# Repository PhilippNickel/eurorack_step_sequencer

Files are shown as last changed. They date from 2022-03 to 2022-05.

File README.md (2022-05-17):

# eurorack_step_sequencer
Open Hardware 8 Channel Eurorack Step Sequencer
# Introduction
These are the KiCad PCB files for a DIY eurorack 8 channel step sequencer module. The heart of the system is an Atmega16A and it features a small i2c OLED Display to modify certain settings. The manufacturing, firmware and testing are still work in progress, photos, videos and firmware will follow.
# 3d Model
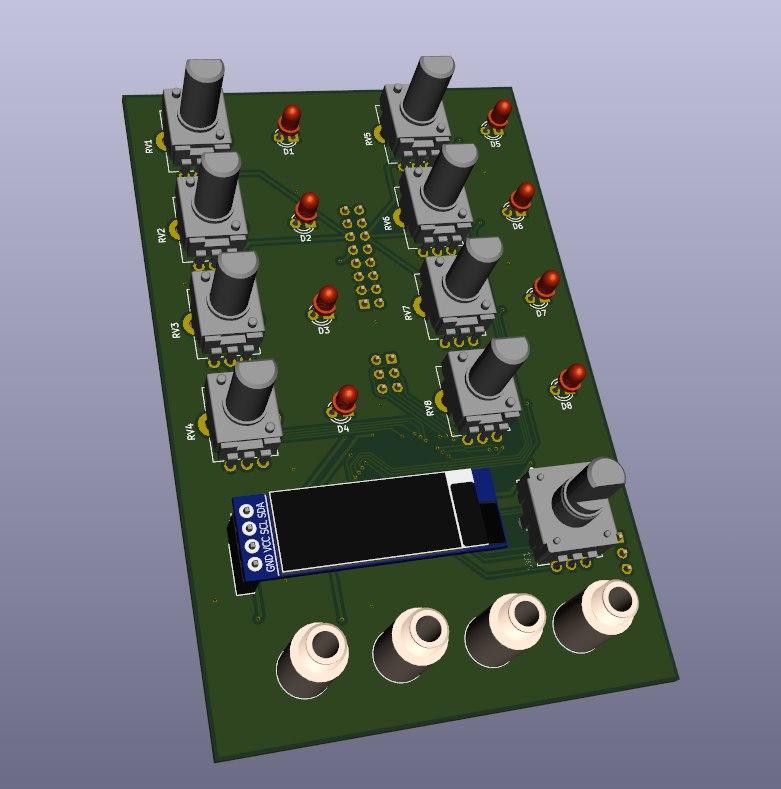
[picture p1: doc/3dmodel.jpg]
3d Model without faceplate 3dmodel


# Schematic
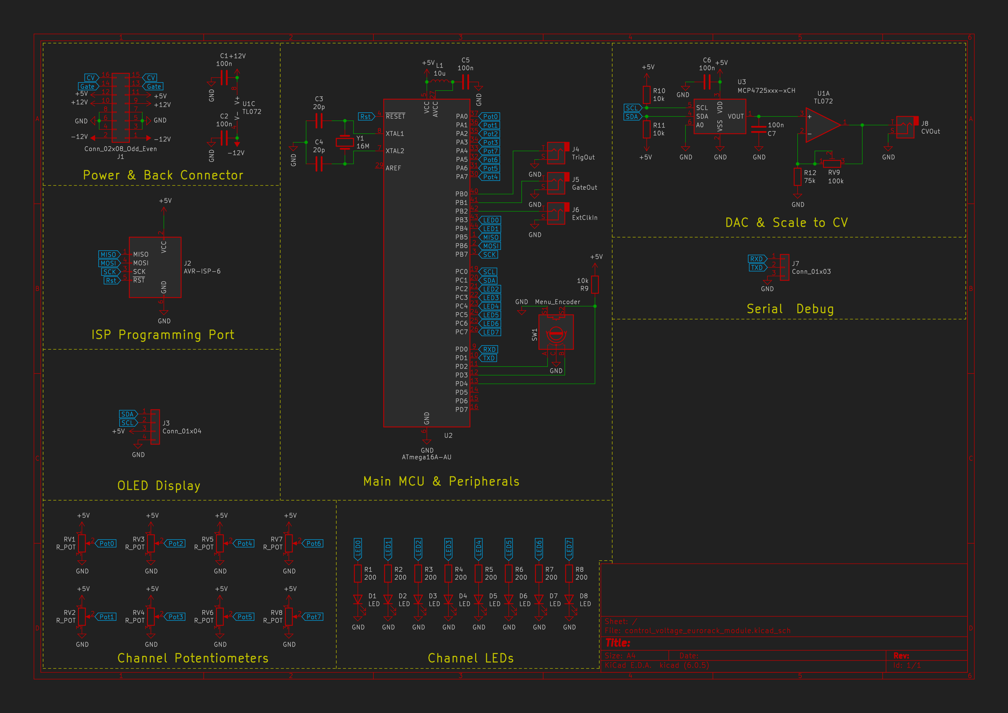
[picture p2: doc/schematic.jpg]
Schematic schematic


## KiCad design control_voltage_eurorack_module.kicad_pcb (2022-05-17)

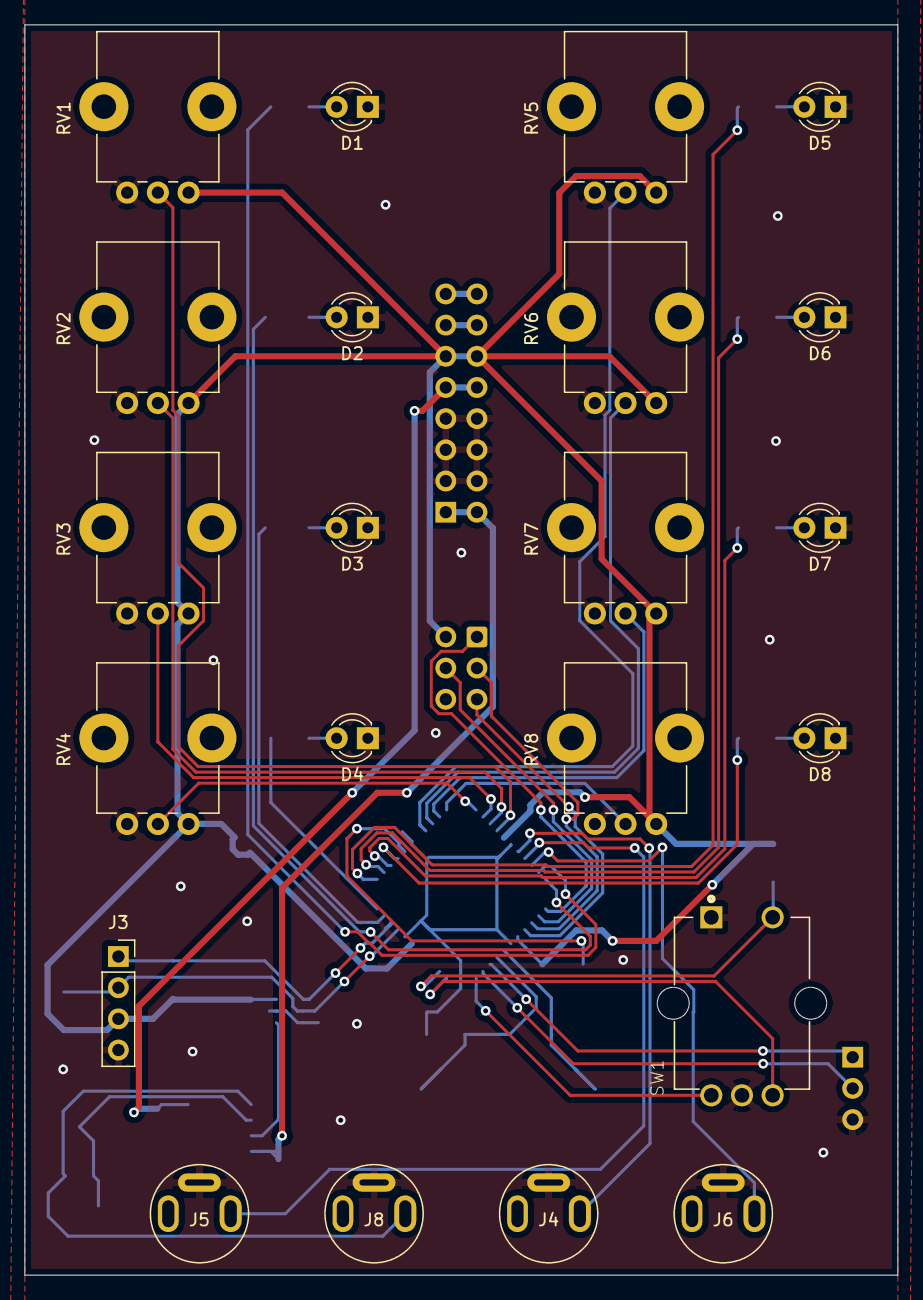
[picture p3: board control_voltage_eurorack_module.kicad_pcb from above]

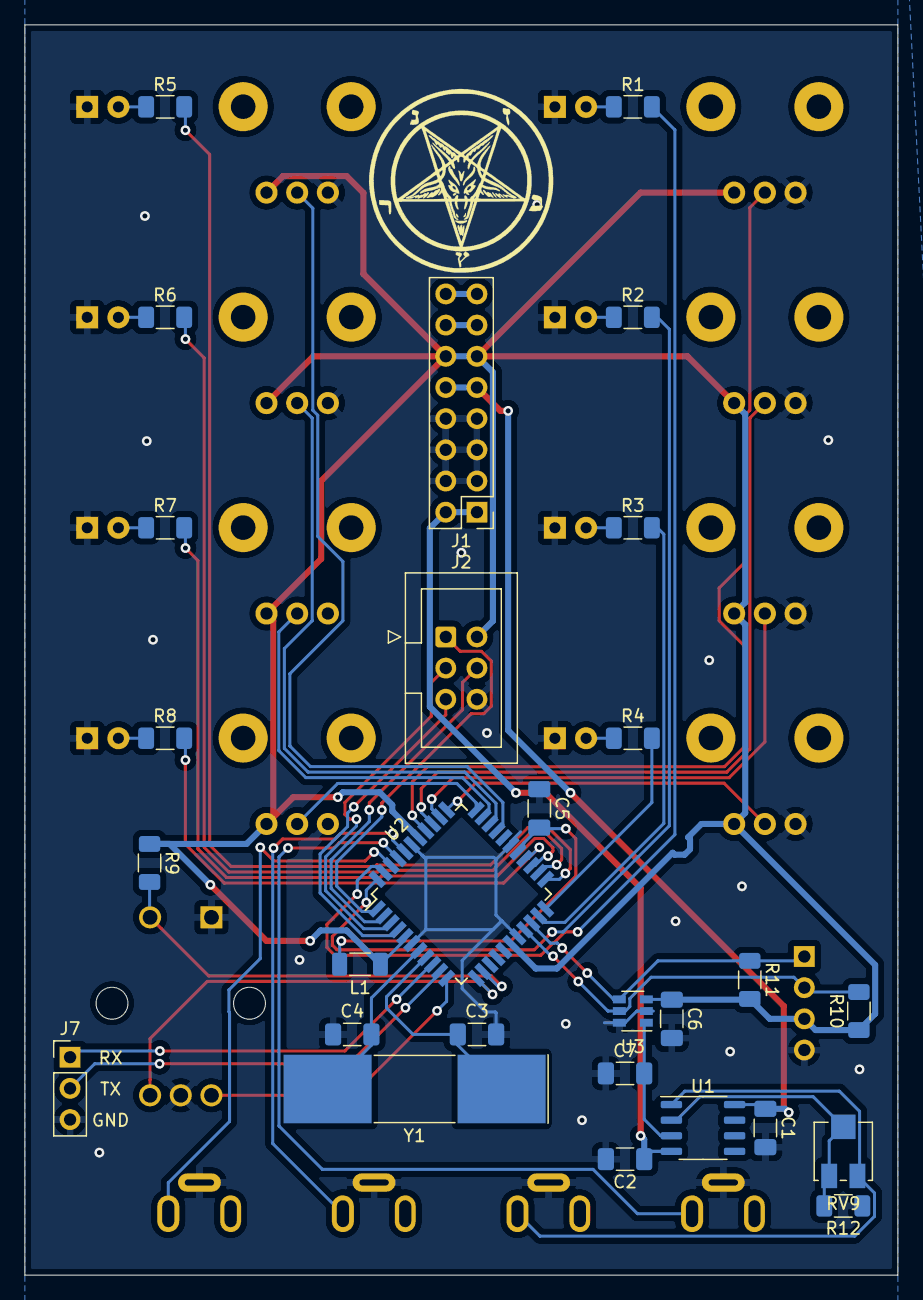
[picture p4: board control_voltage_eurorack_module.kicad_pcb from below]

Board: 2 copper layers, 71.1 x 101.9 mm, 50 parts (28 on the bottom side), 50 nets.

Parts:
C1, C2, C5, C6, C7: 100n; C_1206_3216Metric_Pad1.33x1.80mm_HandSolder
C3, C4: 20p; C_1206_3216Metric_Pad1.33x1.80mm_HandSolder
D1, D2, D3, D4, D5, D6, D7, D8: LED; LED_D3.0mm
J1: Conn_02x08_Odd_Even; PinHeader_2x08_P2.54mm_Vertical
J2: AVR-ISP-6; IDC-Header_2x03_P2.54mm_Vertical
J3: Conn_01x04; PinSocket_1x04_P2.54mm_Vertical
J4: TrigOut; Jack_3.5mm_VERTICAL
J5: GateOut; Jack_3.5mm_VERTICAL
J6: ExtClkIn; Jack_3.5mm_VERTICAL
J7: Conn_01x03; PinHeader_1x03_P2.54mm_Vertical
J8: CVOut; Jack_3.5mm_VERTICAL
L1: 10u; L_1206_3216Metric_Pad1.22x1.90mm_HandSolder
R1, R2, R3, R4, R5, R6, R7, R8: 200; R_1206_3216Metric_Pad1.30x1.75mm_HandSolder
R9, R10, R11: 10k; R_1206_3216Metric_Pad1.30x1.75mm_HandSolder
R12: 75k; R_1206_3216Metric_Pad1.30x1.75mm_HandSolder
RV1, RV2, RV3, RV4, RV5, RV6, RV7, RV8: R_POT; Potentiometer_Bourns_PTV09A-1_Single_Vertical
RV9: 100k; Potentiometer_Bourns_3314J_Vertical
SW1: Menu_Encoder; ENC_PEC12R-4025F-S0024
U1: TL072; SO-8_3.9x4.9mm_P1.27mm
U2: ATmega16A-AU; TQFP-44_10x10mm_P0.8mm
U3: MCP4725xxx-xCH; SOT-23-6
Y1: 16M; Crystal_SMD_SeikoEpson_MA505-2Pin_12.7x5.1mm_HandSoldering

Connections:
+5V: C6.1, J1.11, J1.12, J2.2, J3.3, L1.1, R9.1, R10.1, R11.2, RV1.1, RV2.1, RV3.1, RV4.1, RV5.1, RV6.1, RV7.1, RV8.1, U2.5, U2.17, U2.38, U3.3
+12V: C1.1, J1.9, J1.10, U1.8
-12V: C2.1, J1.1, J1.2, U1.4
CV: J1.15, J1.16
GND: C1.2, C2.2, C3.2, C4.2, C5.1, C6.2, C7.1, D1.1, D2.1, D3.1, D4.1, D5.1, D6.1, D7.1, D8.1, J1.3, J1.4, J1.5, J1.6, J1.7, J1.8, J2.6, J3.4, J4.S, J5.S, J6.S, J7.3, J8.S, R12.1, RV1.3, RV2.3, RV3.3, RV4.3, RV5.3, RV6.3, RV7.3, RV8.3, SW1.C, SW1.S1, U2.6, U2.18, U2.28, U2.39, U3.2, U3.6
Gate: J1.13, J1.14
LED0: R1.2, U2.43
LED1: R2.2, U2.44
LED2: R3.2, U2.21
LED3: R4.2, U2.22
LED4: R5.2, U2.23
LED5: R6.2, U2.24
LED6: R7.2, U2.25
LED7: R8.2, U2.26
MISO: J2.1, U2.1
MOSI: J2.4, U2.2
unnamed: C3.1, U2.8, Y1.1
unnamed: C4.1, U2.7, Y1.2
unnamed: C5.2, L1.2, U2.27
unnamed: C7.2, U1.3, U3.1
unnamed: D1.2, R1.1
unnamed: D2.2, R2.1
unnamed: D3.2, R3.1
unnamed: D4.2, R4.1
unnamed: D5.2, R5.1
unnamed: D6.2, R6.1
unnamed: D7.2, R7.1
unnamed: D8.2, R8.1
unnamed: J4.T, U2.40
unnamed: J5.T, U2.41
unnamed: J6.T, U2.42
unnamed: J8.T, RV9.3, U1.1
unnamed: R9.2, SW1.S2, U2.13
unnamed: R12.2, RV9.1, RV9.2, U1.2
unnamed: SW1.A, U2.11
unnamed: SW1.B, U2.12
Pot0: RV1.2, U2.37
Pot1: RV2.2, U2.36
Pot2: RV3.2, U2.35
Pot3: RV4.2, U2.34
Pot4: RV5.2, U2.30
Pot5: RV6.2, U2.31
Pot6: RV7.2, U2.32
Pot7: RV8.2, U2.33
RXD: J7.1, U2.9
Rst: J2.5, U2.4
SCK: J2.3, U2.3
SCL: J3.2, R10.2, U2.19, U3.5
SDA: J3.1, R11.1, U2.20, U3.4
TXD: J7.2, U2.10

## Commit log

2021-03-28 fixed wrong i2c pins and added uart port
    [control_voltage_eurorack_module.kicad_pcb, control_voltage_eurorack_module.sch]
2021-03-28 added 3d shapes
    [control_voltage_eurorack_module.kicad_pcb]
2022-03-31 updated to kicad 6
    [control_voltage_eurorack_module.kicad_pcb, control_voltage_eurorack_module.kicad_sch]
2022-05-17 added schematic
    [control_voltage_eurorack_module.kicad_pcb]
